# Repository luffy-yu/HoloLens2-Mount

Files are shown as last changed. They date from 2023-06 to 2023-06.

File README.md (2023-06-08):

# HoloLens 2 Mount

## Motivation

- Sometimes I need HoloLens 2 to keep still. It's hard to keep it still when I wear it.
- Based on [Hololens Spectator View Mount](https://www.thingiverse.com/thing:2871324)
- Update some files to adapt HoloLens 2
    - Front
    - Plate
    - Camera-Nut
    - Connector (Add)
    - Washer (Add)
- Included 3ds Max file
- **Welcome PR**

## How it looks like

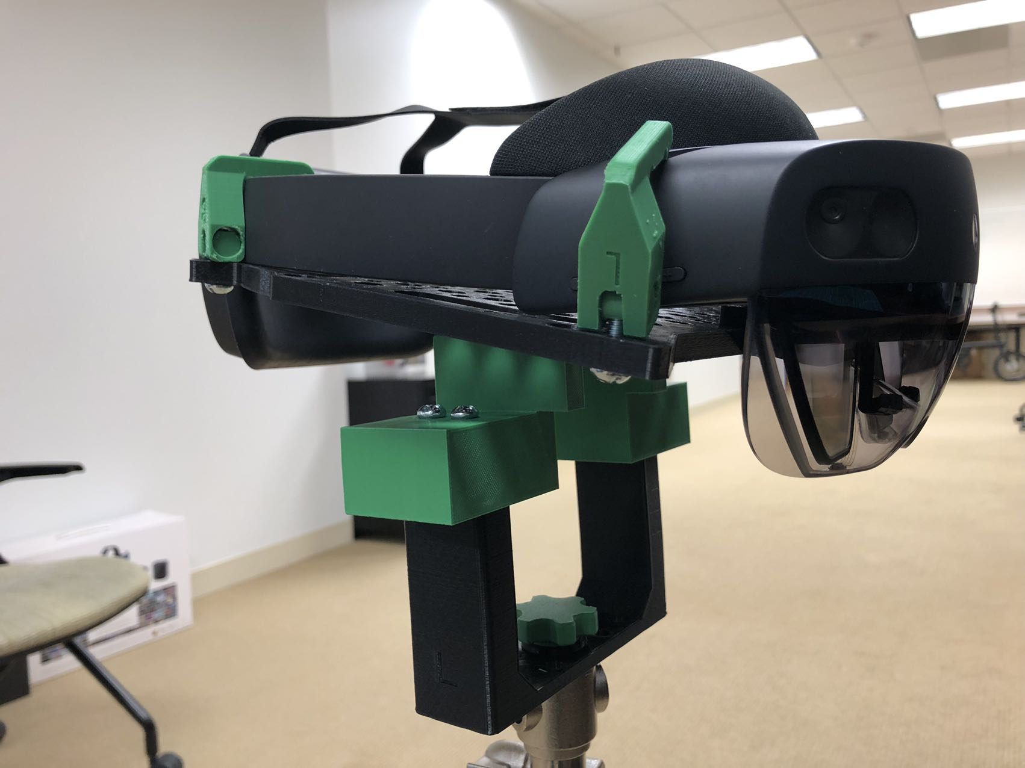
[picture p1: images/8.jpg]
- 
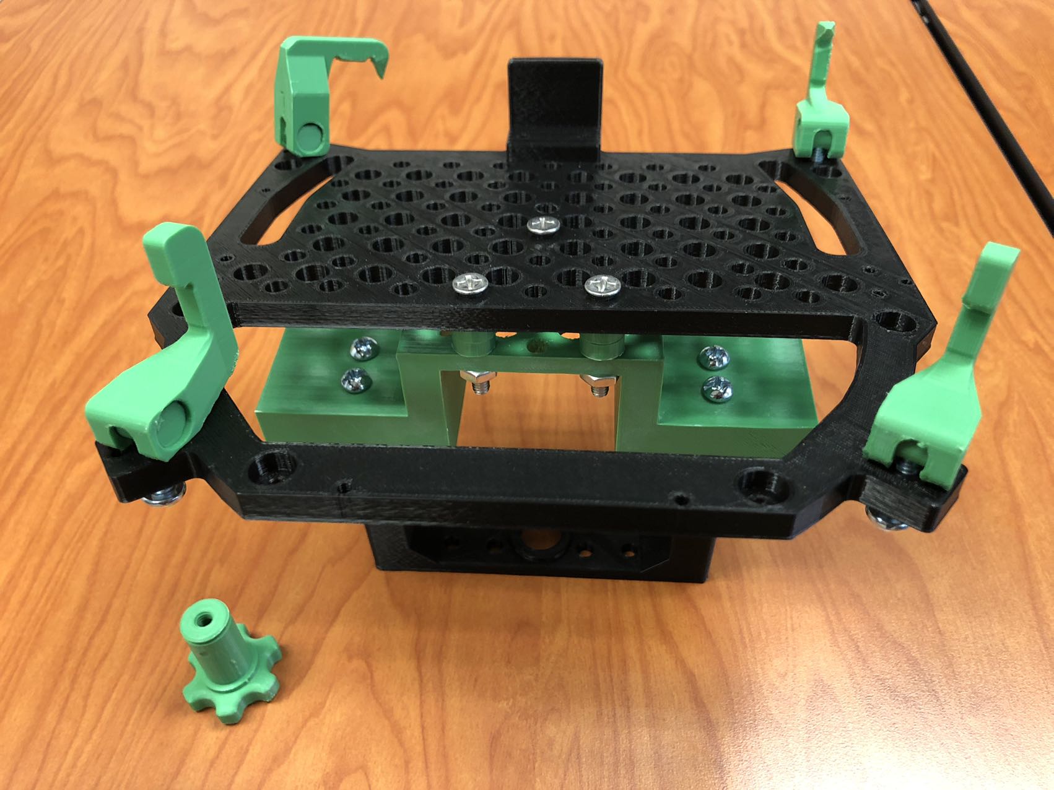
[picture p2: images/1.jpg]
- 
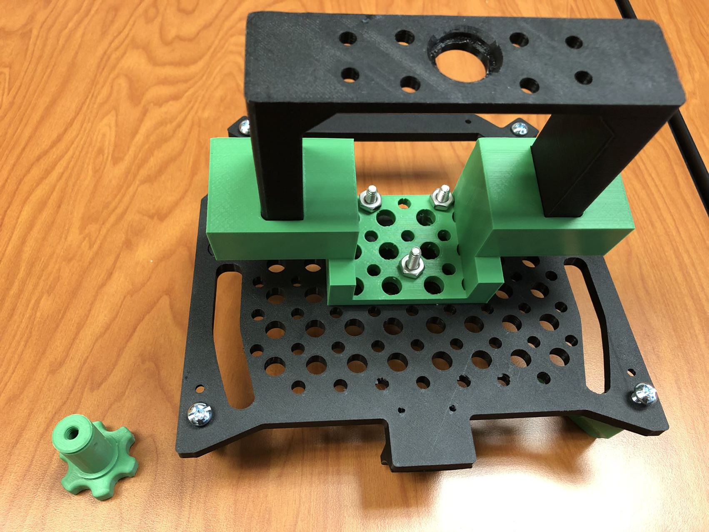
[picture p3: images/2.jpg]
- 
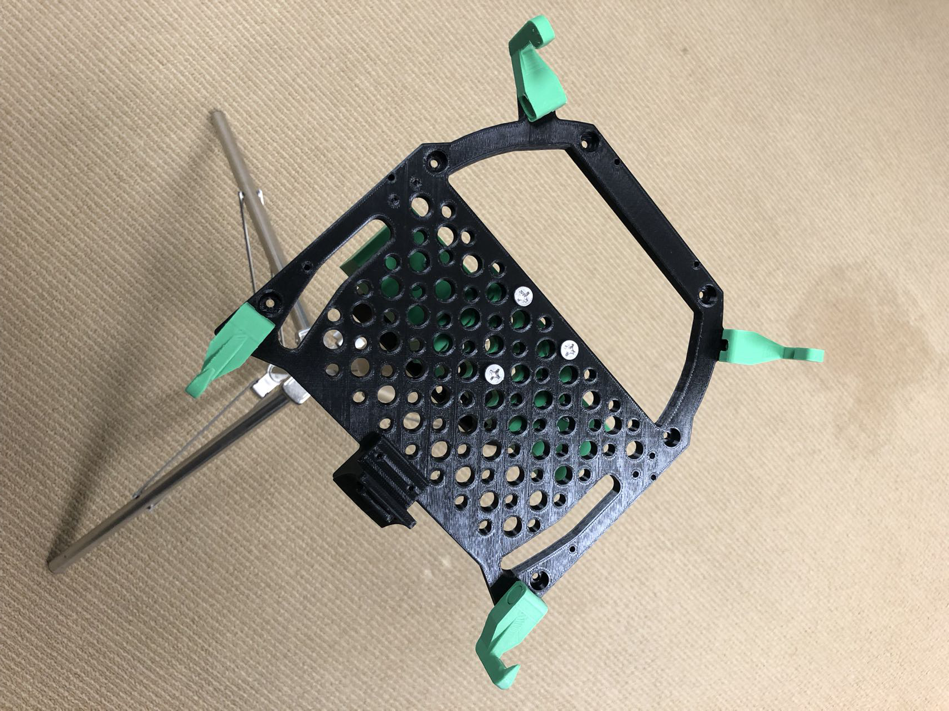
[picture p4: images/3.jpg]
- 
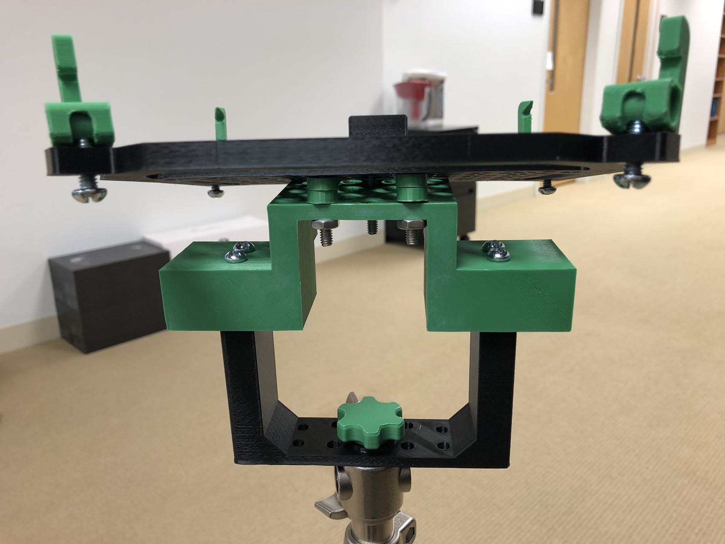
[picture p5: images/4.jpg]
- 
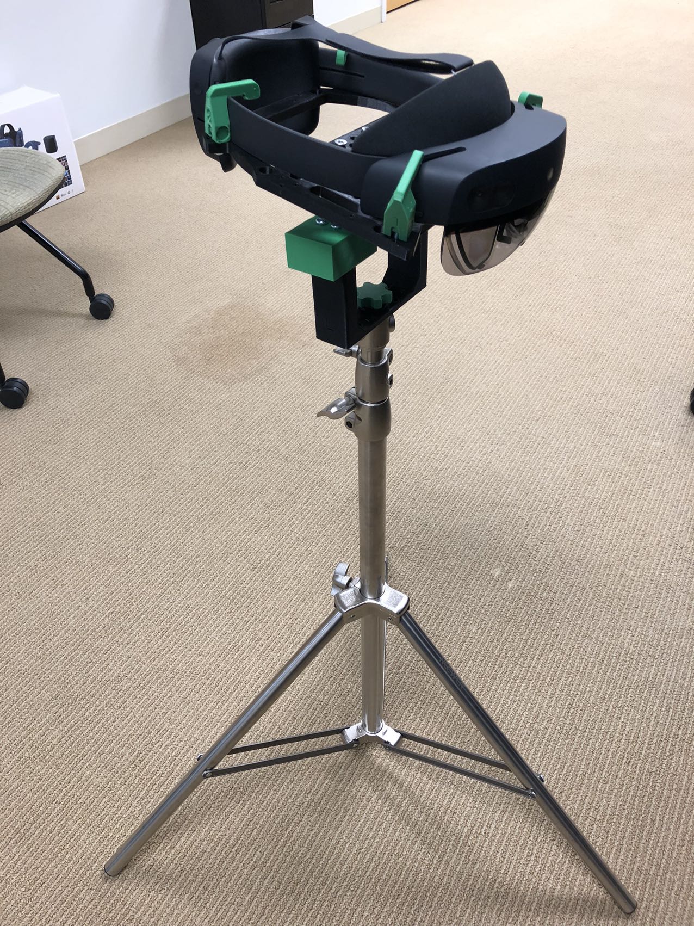
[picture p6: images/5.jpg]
- 
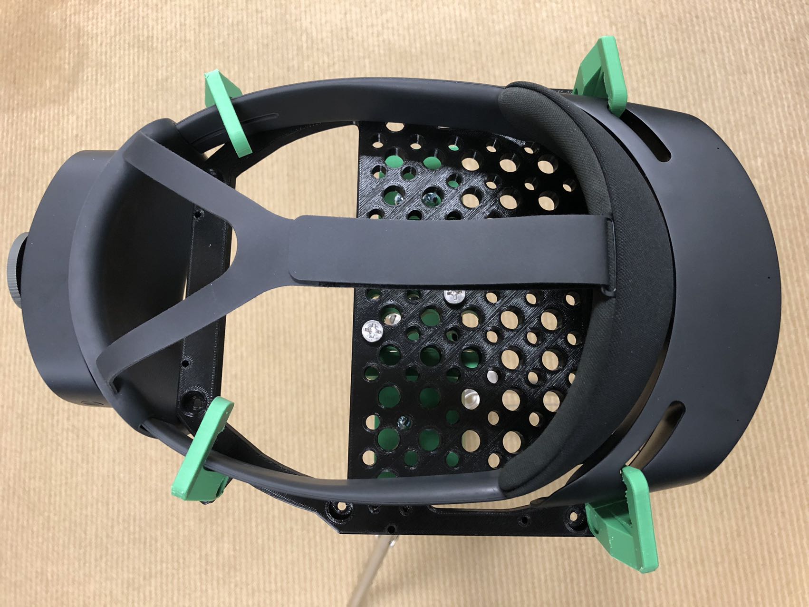
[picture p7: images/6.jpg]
- 
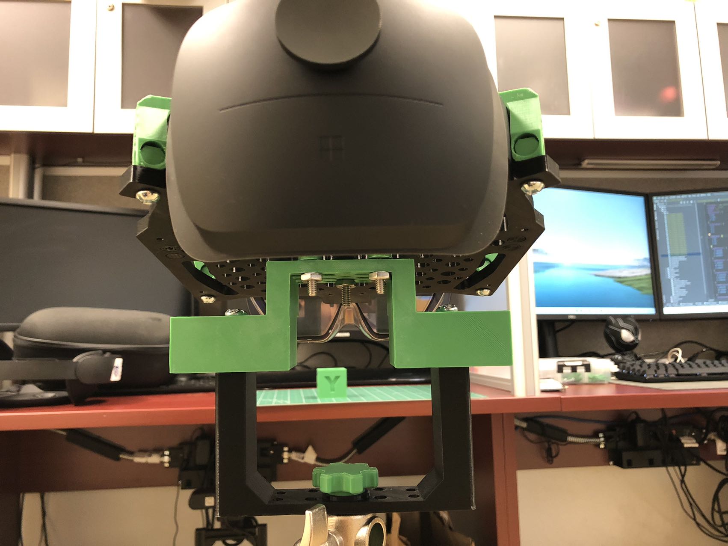
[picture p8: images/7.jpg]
- 

## Preview

> n in "xn" means the needed number to print out.

- Back (x2)
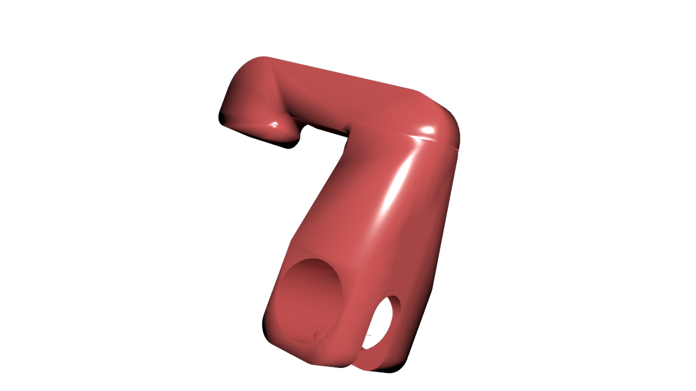
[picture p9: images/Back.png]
  

- C-Clip
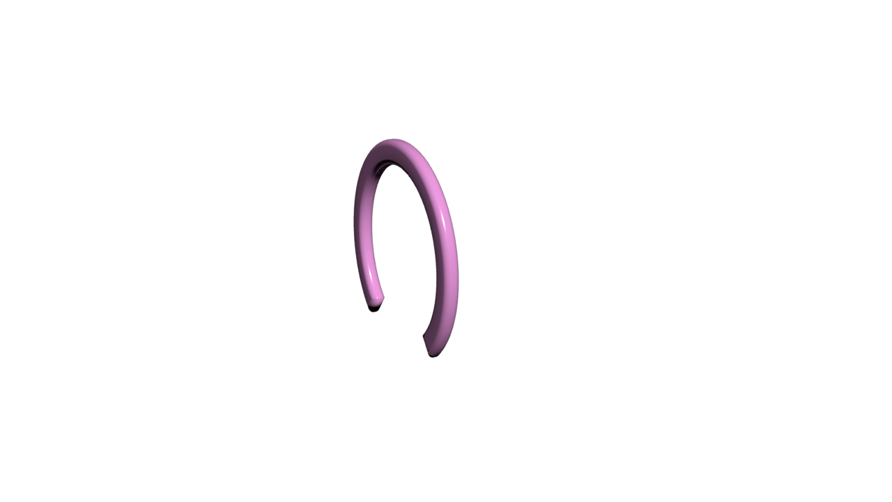
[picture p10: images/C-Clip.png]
  

- Camera-Nut
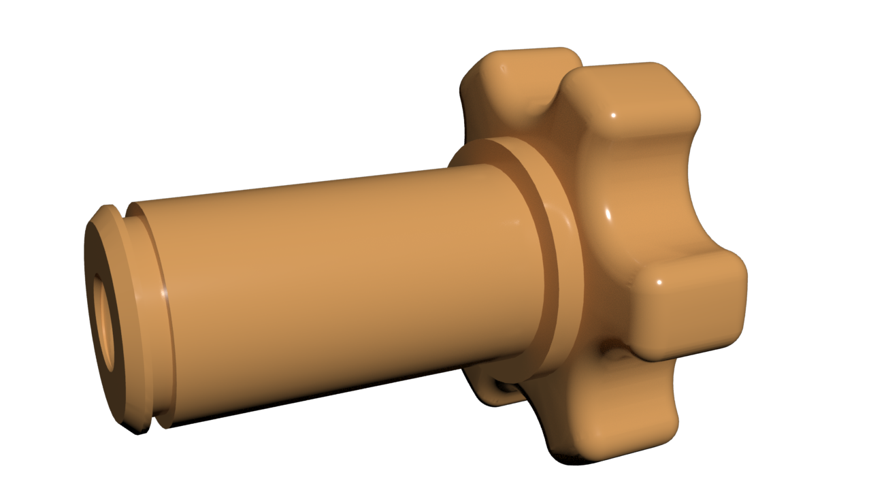
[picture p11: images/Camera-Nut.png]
  

- Connector
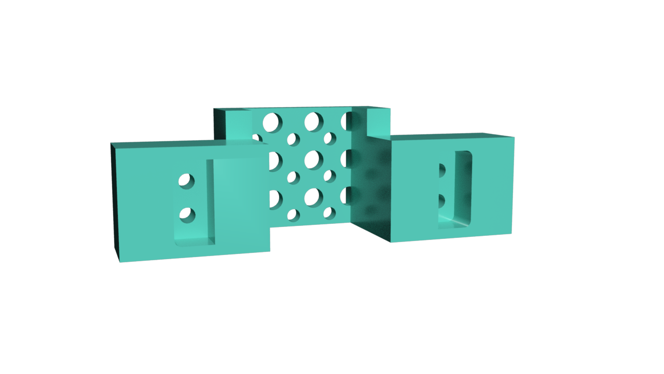
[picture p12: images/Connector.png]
  

- Front (x2)
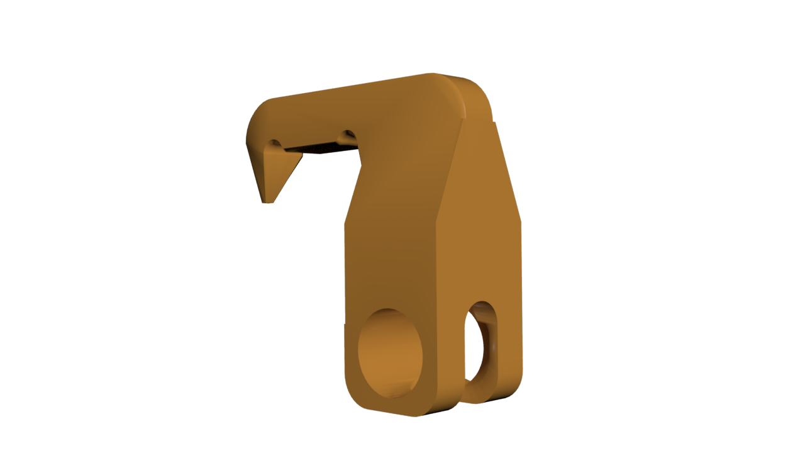
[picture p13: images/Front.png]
  

- Mount
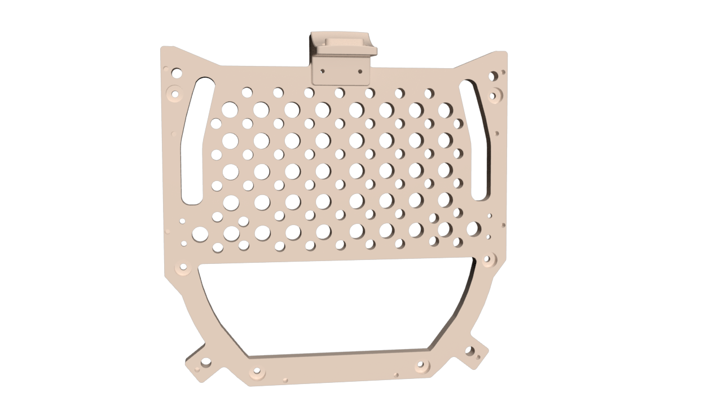
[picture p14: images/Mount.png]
  

- Plate
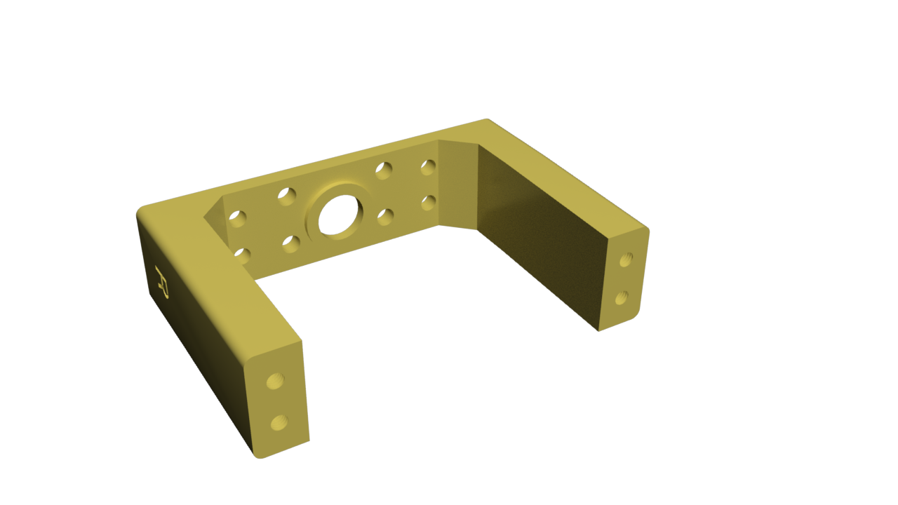
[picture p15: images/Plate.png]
  

- Roll-Pin (x4)
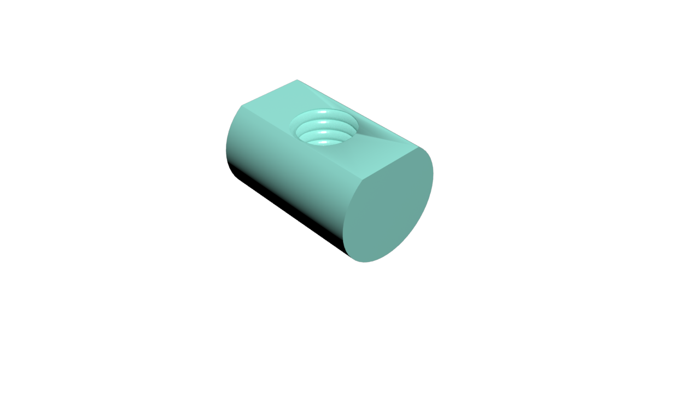
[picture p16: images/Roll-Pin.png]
  

- Washer
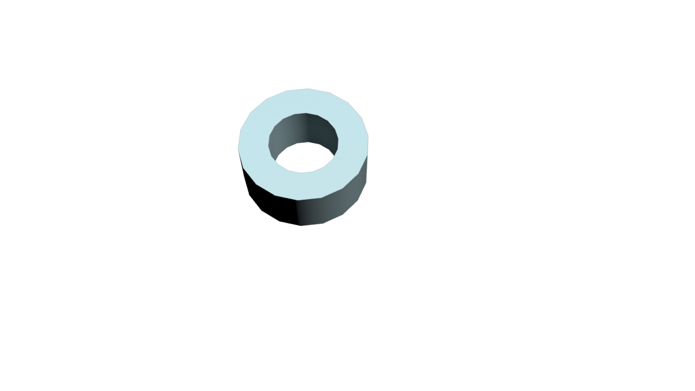
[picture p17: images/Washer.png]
  

## Screws

> I removed screws because 3D printed screws were not strong enough.

I bought some Machine screws from Home Depot.

- [#12-24 x 3/4 in. Zinc Plated Combo Round Head Machine Screw (5-Pack)](https://www.homedepot.com/p/12-24-x-3-4-in-Zinc-Plated-Combo-Round-Head-Machine-Screw-5-Pack-831341/317479110)

> Connect roll-pin and mount (x4)

- [#12-24 x 1 in. Phillips-Slotted Round-Head Machine Screws (4-Pack)](https://www.homedepot.com/p/Everbilt-12-24-x-1-in-Phillips-Slotted-Round-Head-Machine-Screws-4-Pack-831311/317478835)

> Connect connector and plate (x4)

- [#12-24 x 1-1/2 in. Zinc Plated Combo Round Head Machine Screw (4-Pack)](https://www.homedepot.com/p/12-24-x-1-1-2-in-Zinc-Plated-Combo-Round-Head-Machine-Screw-4-Pack-826141/317479111)

> Connect connector and mount (x3).
> It may need some washers.
> This I bought was flat head, but it doesn't matter.

## Download

[files](files/)

## Print Settings

- Connector, Mount, and Plate
    - Resolution: 0.2mm
    - Infill: 40%

- All others
    - Resolution: 0.1mm
    - Infill: 100%

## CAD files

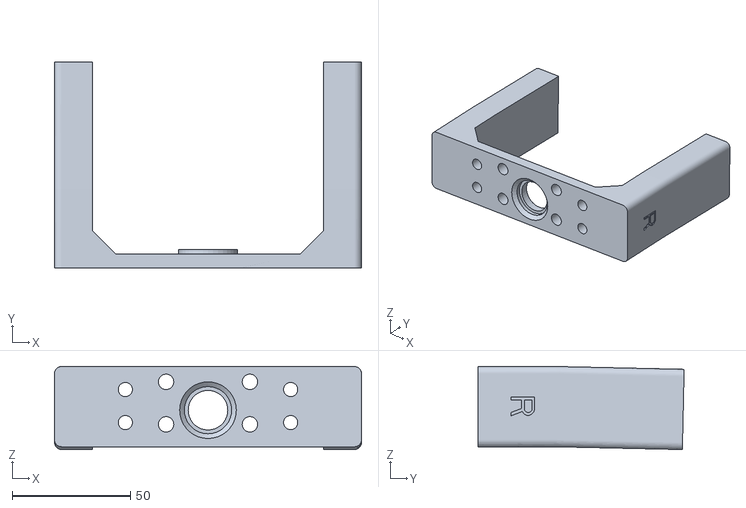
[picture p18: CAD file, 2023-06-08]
files/Plate.stl
130.0 x 87.4 x 35.2

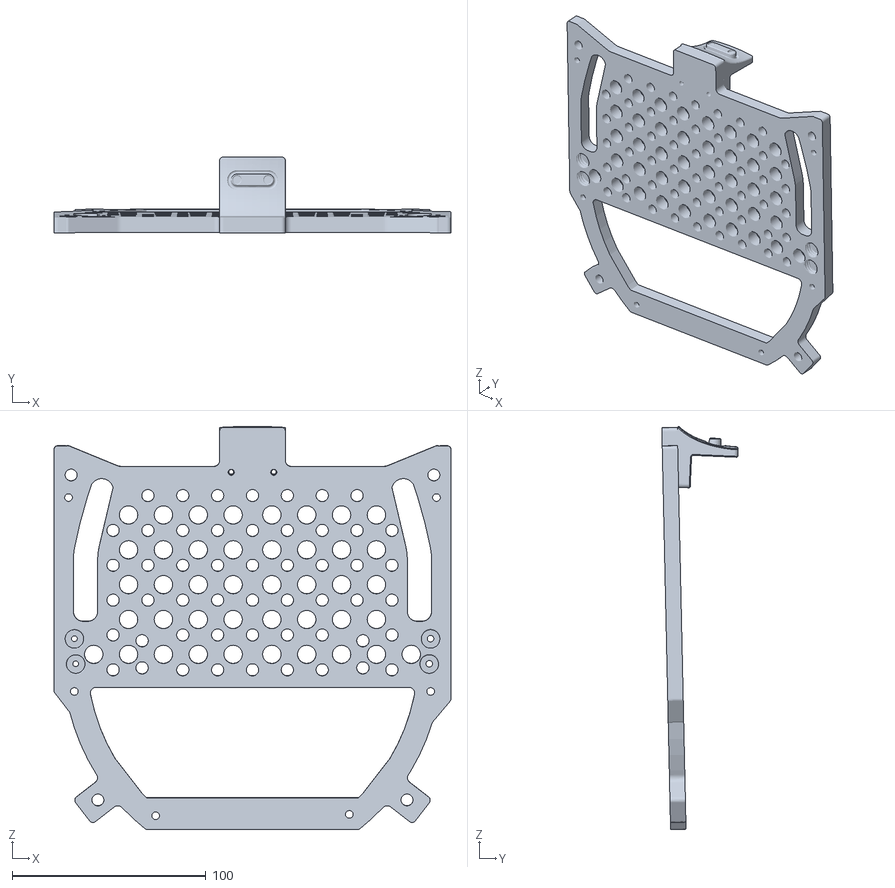
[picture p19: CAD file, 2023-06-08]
files/Mount.stl
205.0 x 39.5 x 208.2

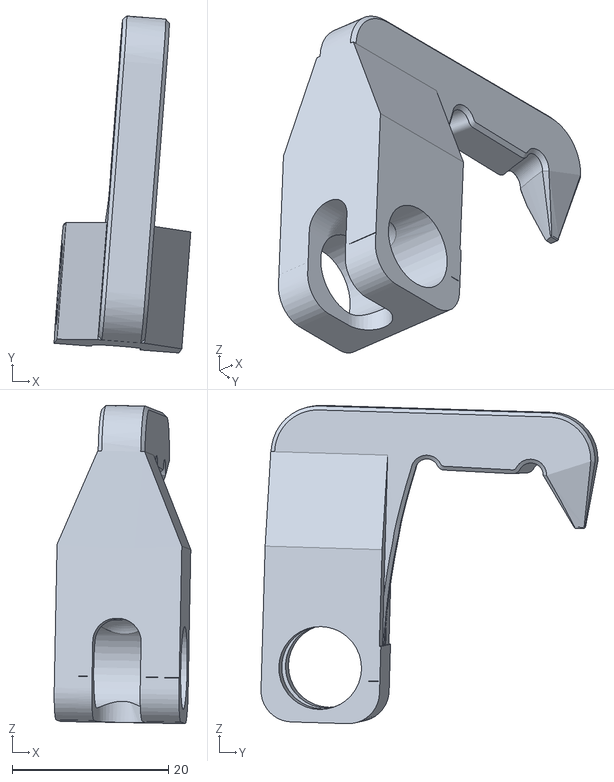
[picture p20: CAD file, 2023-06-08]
files/Front.stl
17.5 x 43.1 x 40.7

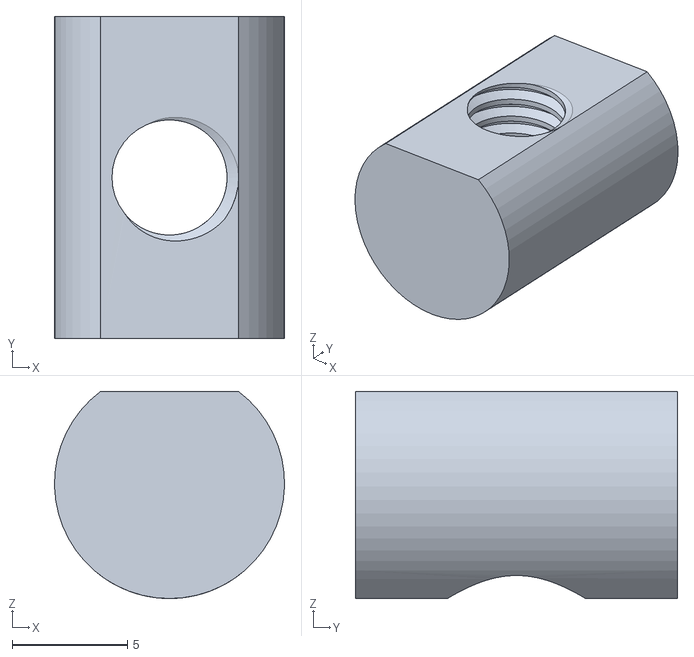
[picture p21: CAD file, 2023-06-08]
files/Roll-Pin.stl
10.00 x 14.0 x 9.00

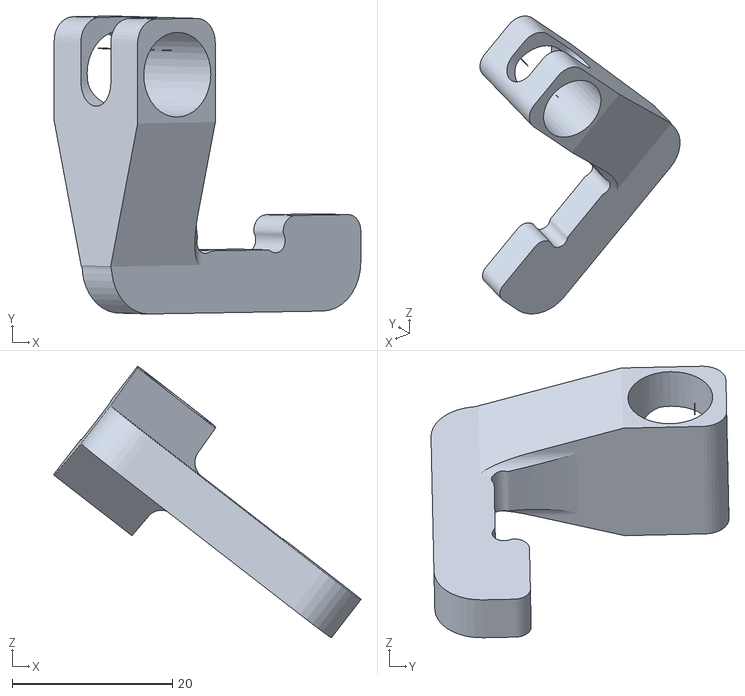
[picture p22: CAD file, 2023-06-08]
files/Back.stl
38.3 x 37.2 x 33.9

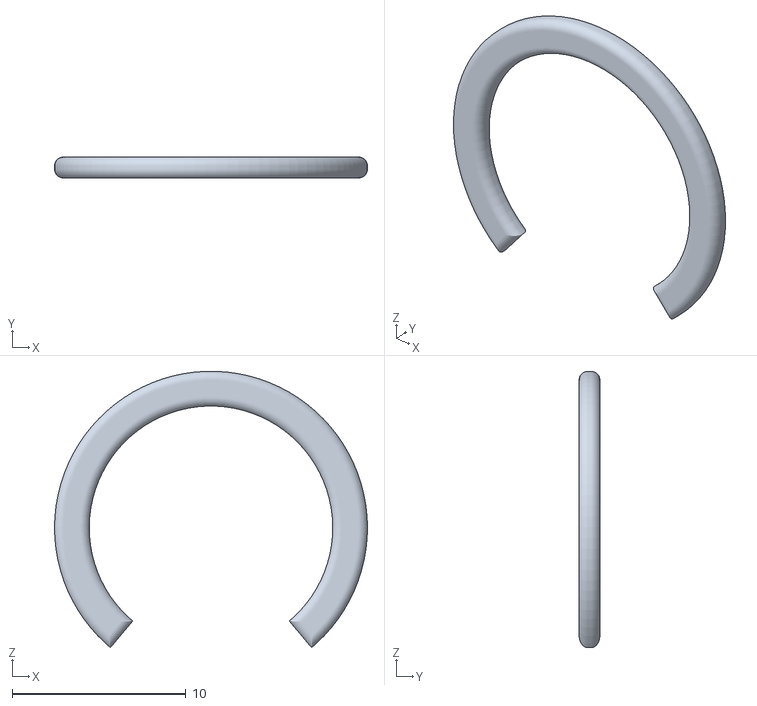
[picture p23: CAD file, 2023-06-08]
files/C-Clip.stl
18.0 x 1.20 x 15.9

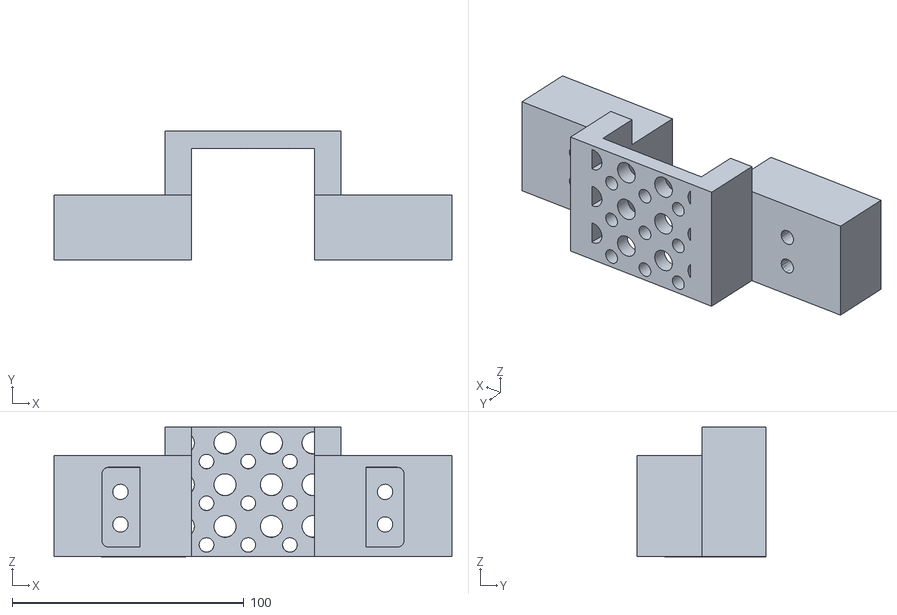
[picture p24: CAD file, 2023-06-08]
files/Connector.stl
171.8 x 55.6 x 56.0

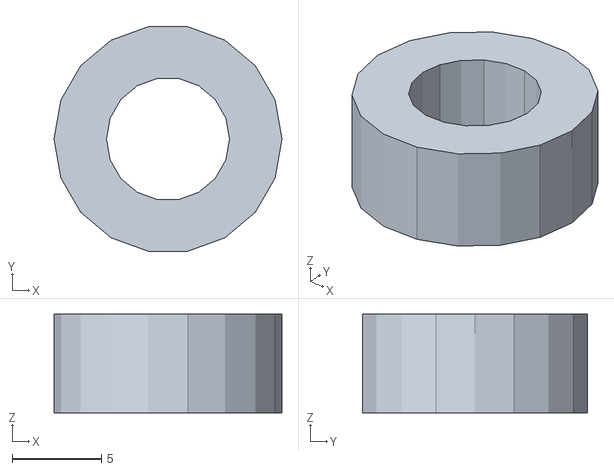
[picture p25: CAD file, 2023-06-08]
files/Washer.stl
12.8 x 12.6 x 5.54

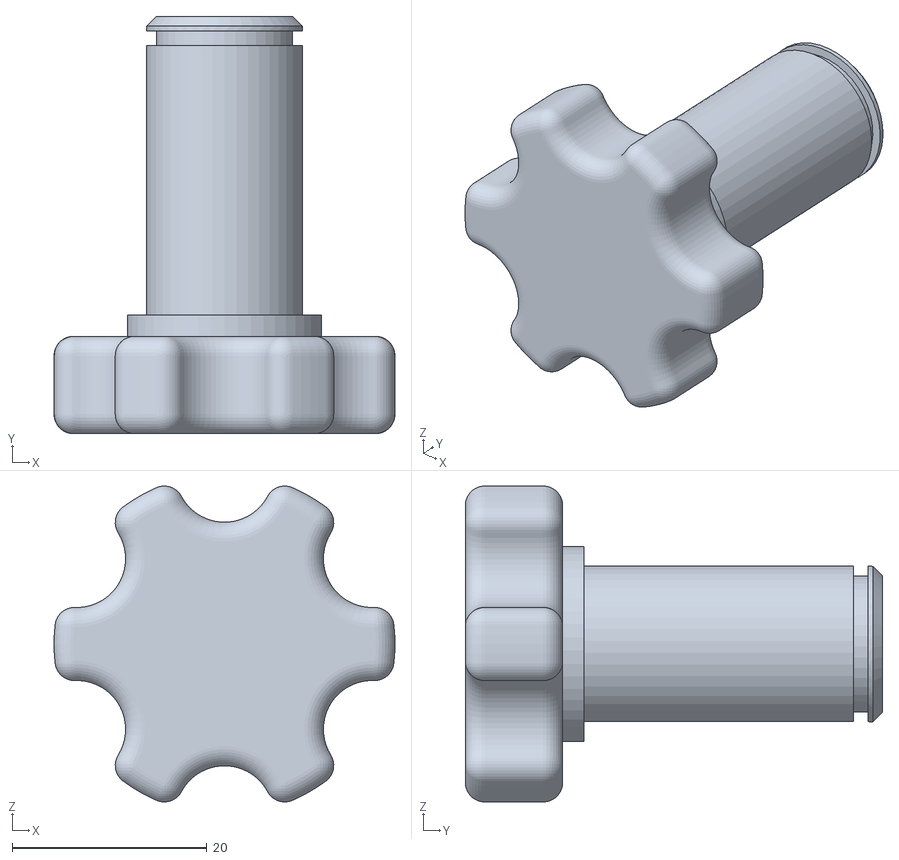
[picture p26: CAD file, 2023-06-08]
files/Camera-Nut.stl
35.0 x 42.8 x 32.4
